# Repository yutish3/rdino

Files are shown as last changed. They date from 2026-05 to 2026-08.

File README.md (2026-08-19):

# Rdino - 2040
rp-2040 development board in the shape of arduino uno r3 so it supports its hats and also has esp32 for wifi and bluetooth and 5x5 grid of neo pixel leds

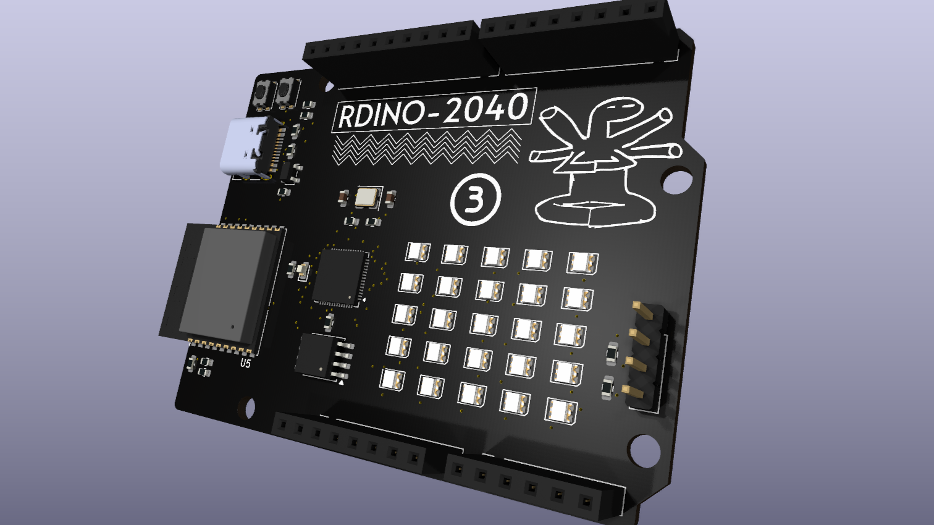
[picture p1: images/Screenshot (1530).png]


## VISION
main goals I had was making it is that I wanted to have a powerful board on which Arduino hats can fit with wireless capabilities so I used both rp 2040 and esp 32 and connected gpios of both so rp 2040 can off load some tasks to esp 32. so in a sense it is like Arduino UNO but on steroids 

and for usage too it can be used like a normal Arduino UNO 

it has dual microcontroller so all the less important repetative tasks can be off loaded to esp32 and main work can be done by the rp 2040 chip with extra 16M bit memory
and it can be used foor any project like lfr robot , micromouse , rc car etc

## what makes it special (main components)
&#9679; RP2040 :- main microcontroller

&#9679; W25Q128JVS :- 128Mbit Flash Memory for extra juice

&#9679; ESP32-C3-WROOM-02 :- backup microcontroller with wifi and Bluetooth capabilities 

&#9679; 25 X WS2812B-2020 :- programmable rgb leds

## Images

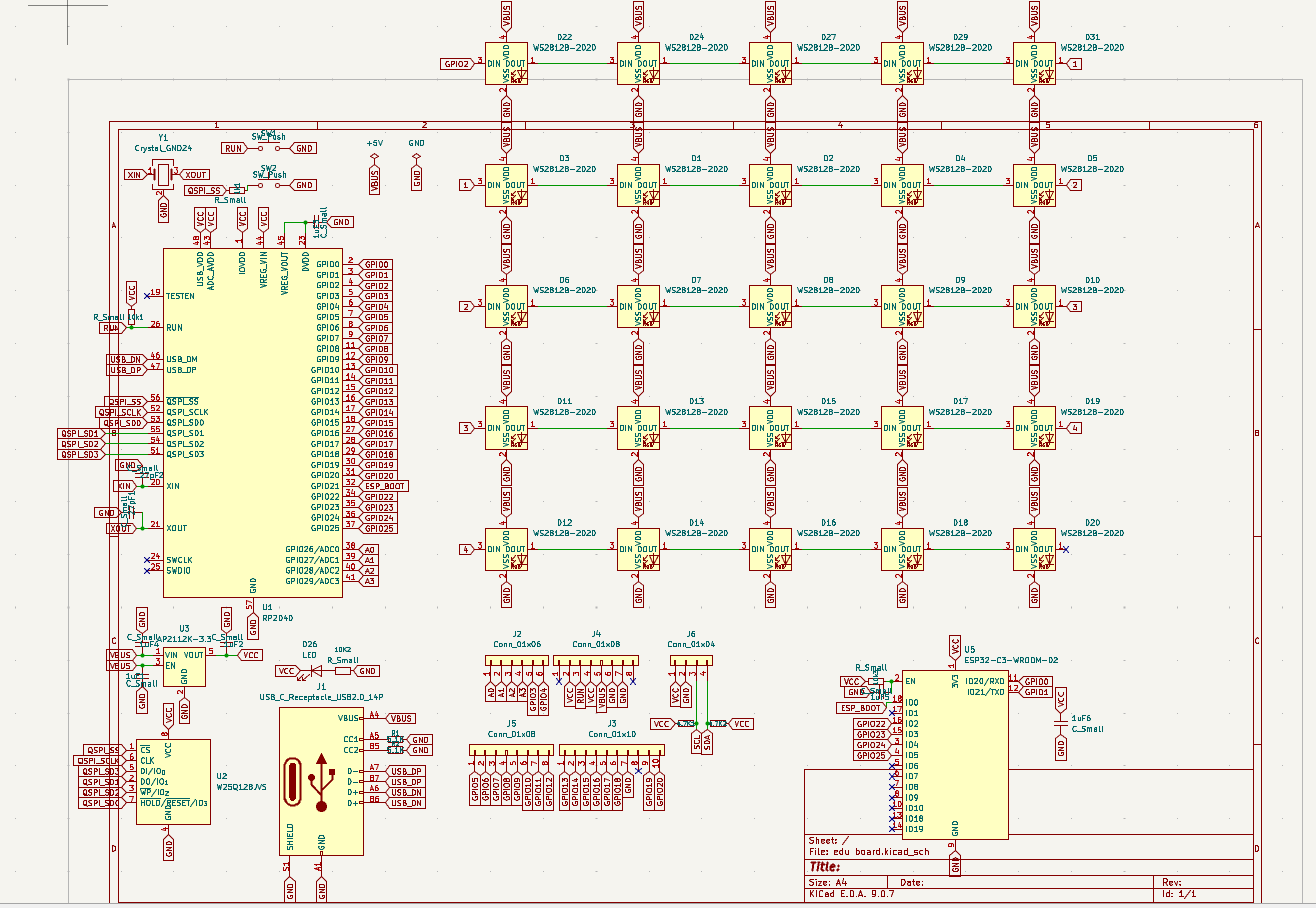
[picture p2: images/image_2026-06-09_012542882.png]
Schematics


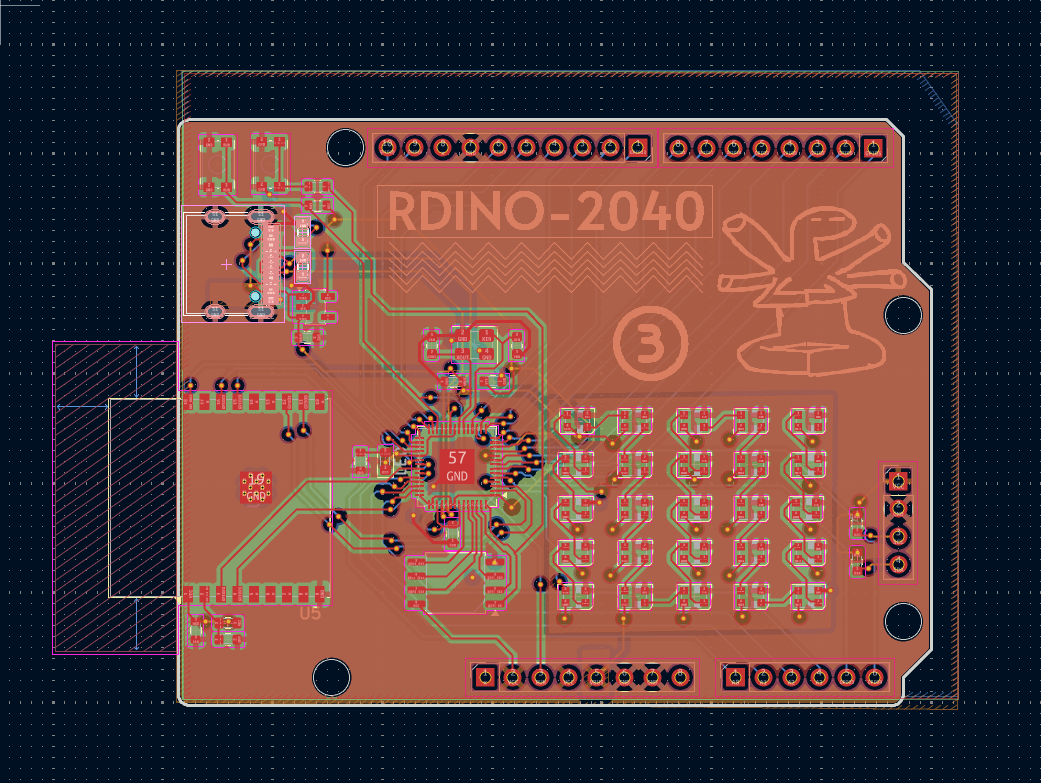
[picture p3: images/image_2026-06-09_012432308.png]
PCB design


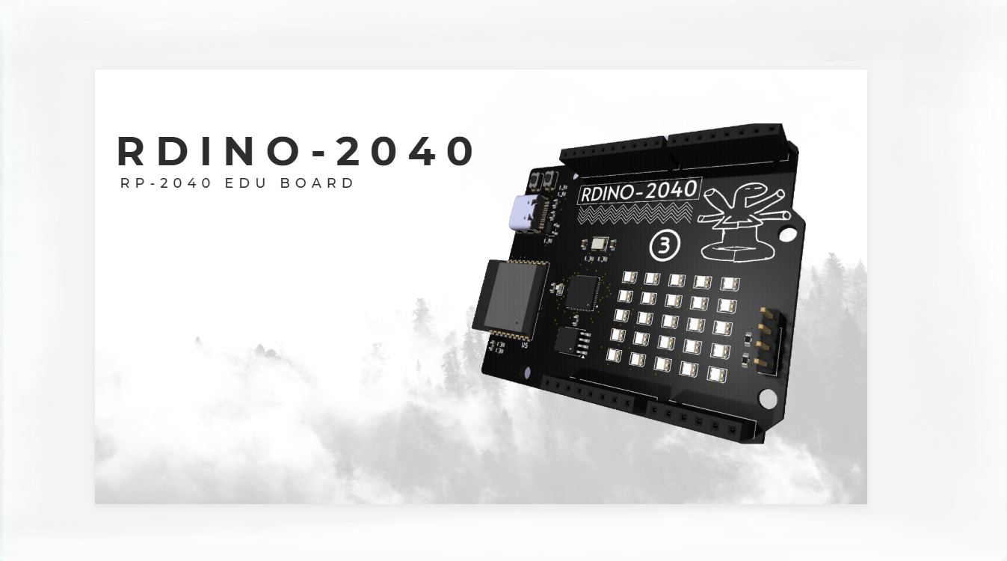
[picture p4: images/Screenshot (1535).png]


PCB Layout 1

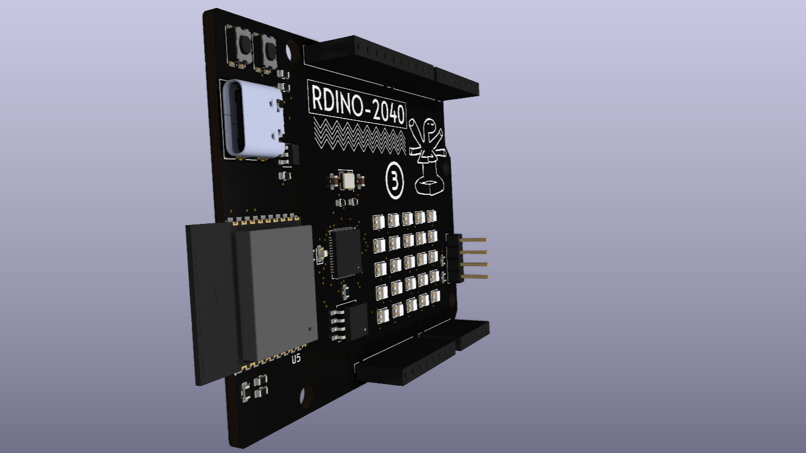
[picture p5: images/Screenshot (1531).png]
PCB Layout 2


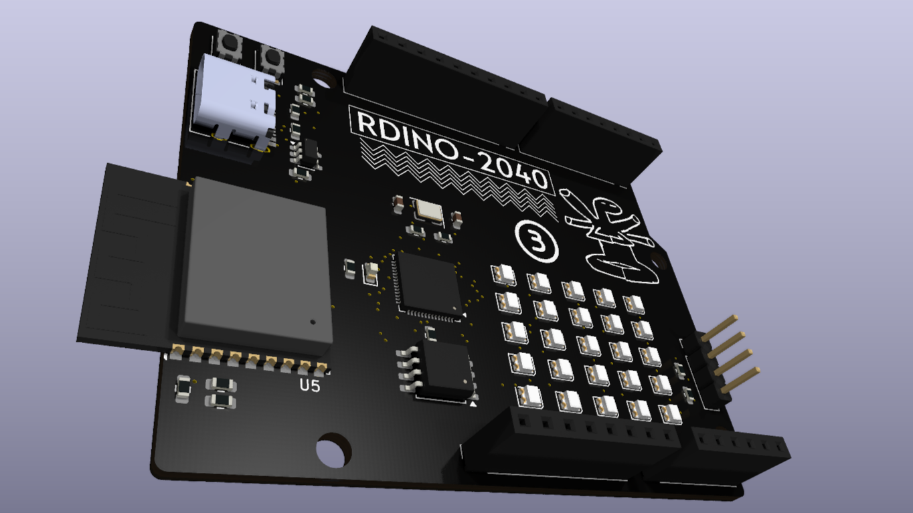
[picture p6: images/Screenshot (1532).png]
DRC Errors


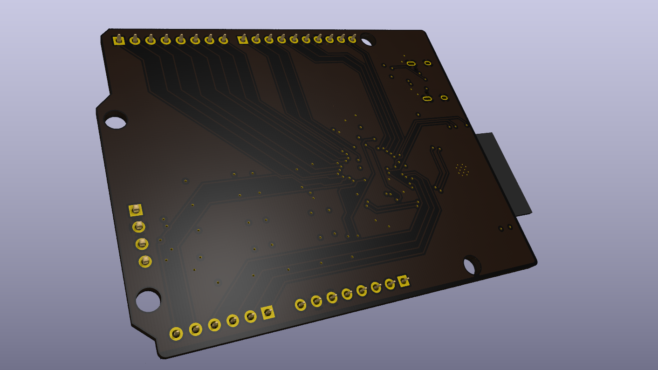
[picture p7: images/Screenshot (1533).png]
Silkscreen Design


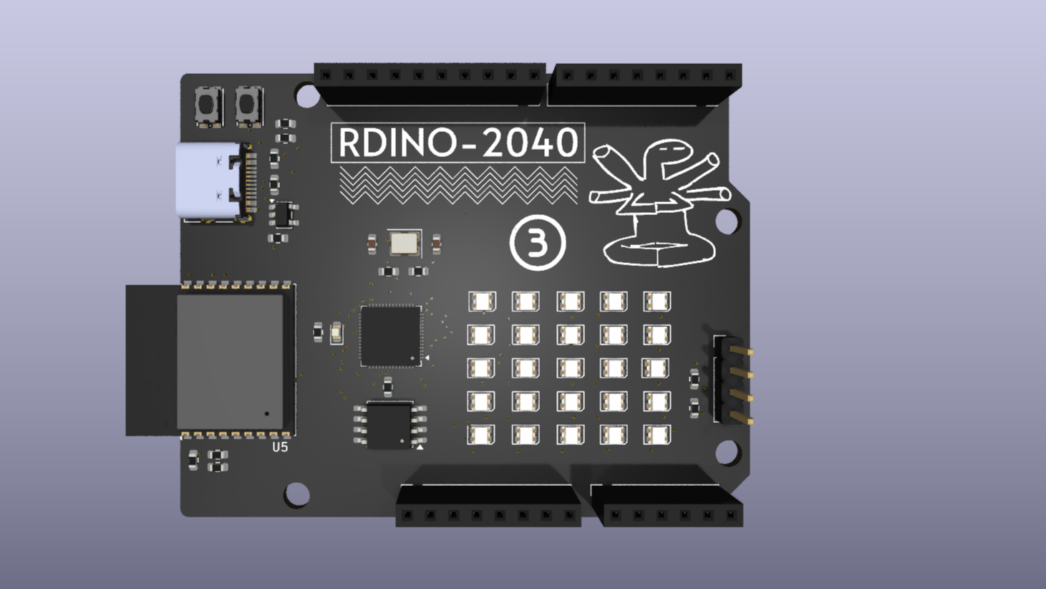
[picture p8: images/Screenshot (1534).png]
3D View


| Component | Purpose | Qty | Cost (INR) | Distributor |
| --- | --- | --- | --- | --- |
| RP2040 (QFN-56) | Main Microcontroller | 1 | ₹81.00 | [Evelta](https://evelta.com/rp2040-264kb-sram-dual-arm-cortex-m0-processor-mcu-by-raspberry-pi/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) |
| ESP32-C3-WROOM-02 | Wi-Fi / BLE Module | 1 | ₹312 | [Evelta](https://evelta.com/esp32-c3-wroom-02-n4-wi-fi-ble-module-4mb-flash-pcb-antenna/?sku=136-ESP32-C3-WROOM-02-N4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) |
| W25Q128JVS (SOIC-8) | 128Mbit Flash Memory | 1 | ₹223 | [Evelta](https://evelta.com/serial-nor-flash-memory-128mbit-8pin-soic/?sku=153-W25Q128JVSIQ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) |
| AP2112K-3.3 (SOT-23-5) | 3.3V LDO Voltage Regulator | 1 | ₹24 | [Evelta](https://evelta.com/linear-voltage-regulator-positive-fixed-1-output-300ma-ic-sot-23-5/?sku=035-TLV74033PDBVR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) |
| WS2812B-2020 (PLCC4) | Addressable RGB LEDs (D1-D24, D27, D29, D31) | 25 | ₹275 | [Robu](https://robu.in/product/1-month-warranty-953/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) |
| 74AHCT125 | 3.3v to 5v converter | 1 | ₹113 | [Lioncircuit](https://www.lioncircuits.com/parts/74AHCT125PW%2C118) |
| Standard LED (0603) | Status Indicator (D26) | 1 | ₹3.3 | [evelta](https://evelta.com/0603-orange-chip-led/?srsltid=AfmBOopJK48IT0WFYCzFETDcCPIIkiPRop17X2j5vajIVfQTBZ31vxPa) |
| USB-C Receptacle 14-Pin | Power and Data Interface (J1) | 1 | ₹8 | [Hubtronics](https://hubtronics.in/usb-type-c-16p-female-connector-surface-mount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) |
| 1x04 Pin Header/Socket | I/O Expansion / Programming (J6) | 1 | ₹11 | [Robu](https://robu.in/product/fh2-0-09-04pzd-xunpu-plugin1x4-pin-2mm-female-headers-rohs/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)|
| 1x06 Pin Header/Socket | I/O Expansion (J2) | 5 | ₹53 | [Robu](https://robu.in/product/6-pin-female-11mm-tall-stackable-header-connector-for-arduino-5pcs/) |
| 1x08 Pin Header/Socket | I/O Expansion (J4, J5) | 2 | ₹32 | [Robu](https://robu.in/product/fh1-27-01-08pzd-xunpu-plugin1x8-pin-1-27mm-female-headers-rohs/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) |
| 1x10 Pin Header/Socket | I/O Expansion (J3) | 1 | ₹17 | [Robu](https://robu.in/product/fh1-27-01-10pzd-xunpu-plugin1x10-pin-1-27mm-female-headers-rohs/) |
| Push Button (KMR2) | Reset / User Input (SW1, SW2) | 2 | ₹126 | [Robu](https://robu.in/product/kmr221nglfs-ck-2-8mm-0-5mm-round-button-50ma-vertical-welding-4-2mm-spst-2n-32v-smd-tactile-switches-rohs/) |
| 1.1kΩ Resistor (0603) | Current Limiting / Pull-up | 1 | ₹1 | [Robu](https://robu.in/product/0603waj0112t5e-uniohm-royal-ohm-100mw-thick-film-resistors-75v-%C2%B1100ppm-%E2%84%83%C2%B15-1-1k%CF%89-0603-chip-resistor-surface-mount-rohs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) |
| 4.7kΩ Resistor (0603) | I2C / General Pull-up | 2 | ₹5 | [Robu](https://robu.in/product/rt0603brd074k7l-yageo-res-thin-film-0603-4-7k-ohm-0-1-0-1w1-10w-%C2%B125ppm-c-pad-smd-t-r/) |
| 10kΩ Resistor (0603) | Pull-up / Pull-down | 3 | ₹3 | [Robu](https://robu.in/product/10k-ohm-1-4w-0603-surface-mount-chip-resistor-pack-of-100/) |
| 5.1kΩ Resistor (0603) | USB-C CC line Pull-down | 2 | ₹3 | [Robu](https://robu.in/product/rt0603fre075k1l-yageo-100mw-thin-film-resistor-75v-%C2%B150ppm-%E2%84%83-%C2%B11-5-1k%CF%89-0603-chip-resistor-surface-mount-rohs/) |
| 1μF Capacitor (0603) | Decoupling / Bypass | 6 | ₹8.5 | [Robu](https://robu.in/product/1uf-1000nf-50v-capacitor-0603-smd-package-pack-of-20/) |
| 10pF Capacitor (0603) | Crystal Load Capacitors | 2 | ₹1 | [Robu](https://robu.in/product/10pf-0603-surface-mount-multilayer-ceramic-capacitor-pack-of-50/) |
| Crystal 3225 (4-Pin) | Clock Source for RP2040 (Y1) | 1 | ₹101 | [lion circuit](https://www.lioncircuits.com/parts/NX3225SA-12MHZ-STD-CSR-6) |
| PCB | PCB | 1 | ₹3375 | [Robu] |
| Hot plate | soldering | 1 | ₹2,749 | [Amazon](https://www.amazon.in/Preheating-Soldering-Preheater-Platform-56x56x35mm/dp/B0C7W3W8C4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) |
| soldering flux | gooye paste to combine components | 1 | ₹400 | [amazon](https://www.amazon.in/Electron-Soldering-Syringe-No-Clean-Electronics/dp/B0GTMJHBJ4) |

The Bare Components : ₹1,708.80

PCB Fabrication (Robu): ₹3,375.00

Assembly Tools (Amazon): ₹3,262.00

Grand Total: ₹8,345.8

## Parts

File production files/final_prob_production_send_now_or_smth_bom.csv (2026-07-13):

Designator | Footprint | Quantity | Value | LCSC Part #
10K1, 10K2, 10K3, 1K1, 4.7K1, 4.7K2 | 0603 | 6 | R_Small
10PF1, 10PF2, 1UF1, 1UF2, 1UF3, 1UF4, 1UF5, 1UF6 | 0603 | 8 | C_Small
D1, D10, D11, D12, D13, D14, D15, D16, D17, D18, D19, D2, D20, D22, D24, D27, D29, D3, D31, D4, D5, D6, D7, D8, D9 | LED_WS2812B-2020_PLCC4_2.0x2.0mm | 25 | WS2812B-2020
D26 | 0603 | 1 | LED
J1 | USB_C_Receptacle_HRO_TYPE-C-31-M-12 | 1 | USB_C_Receptacle_USB2.0_14P
J2 | PinSocket_1x06_P2.54mm_Vertical | 1 | Conn_01x06
J3 | PinSocket_1x10_P2.54mm_Vertical | 1 | Conn_01x10
J4, J5 | PinSocket_1x08_P2.54mm_Vertical | 2 | Conn_01x08
J6 | PinHeader_1x04_P2.54mm_Vertical | 1 | Conn_01x04
R1, R2 | 0603 | 2 | 5.1K
SW1, SW2 | SW_Push_1P1T_NO_CK_KMR2 | 2 | SW_Push
U1 | QFN-56-1EP_7x7mm_P0.4mm_EP3.2x3.2mm | 1 | RP2040
U2 | SOIC-8_5.3x5.3mm_P1.27mm | 1 | W25Q128JVS
U3 | SOT-23-5 | 1 | AP2112K-3.3
U4 | TSSOP-14_4.4x5mm_P0.65mm | 1 | 74AHCT125
U5 | ESP32-C3-WROOM-02 | 1 | ESP32-C3-WROOM-02
Y1 | Crystal_SMD_3225-4Pin_3.2x2.5mm | 1 | Crystal_GND24

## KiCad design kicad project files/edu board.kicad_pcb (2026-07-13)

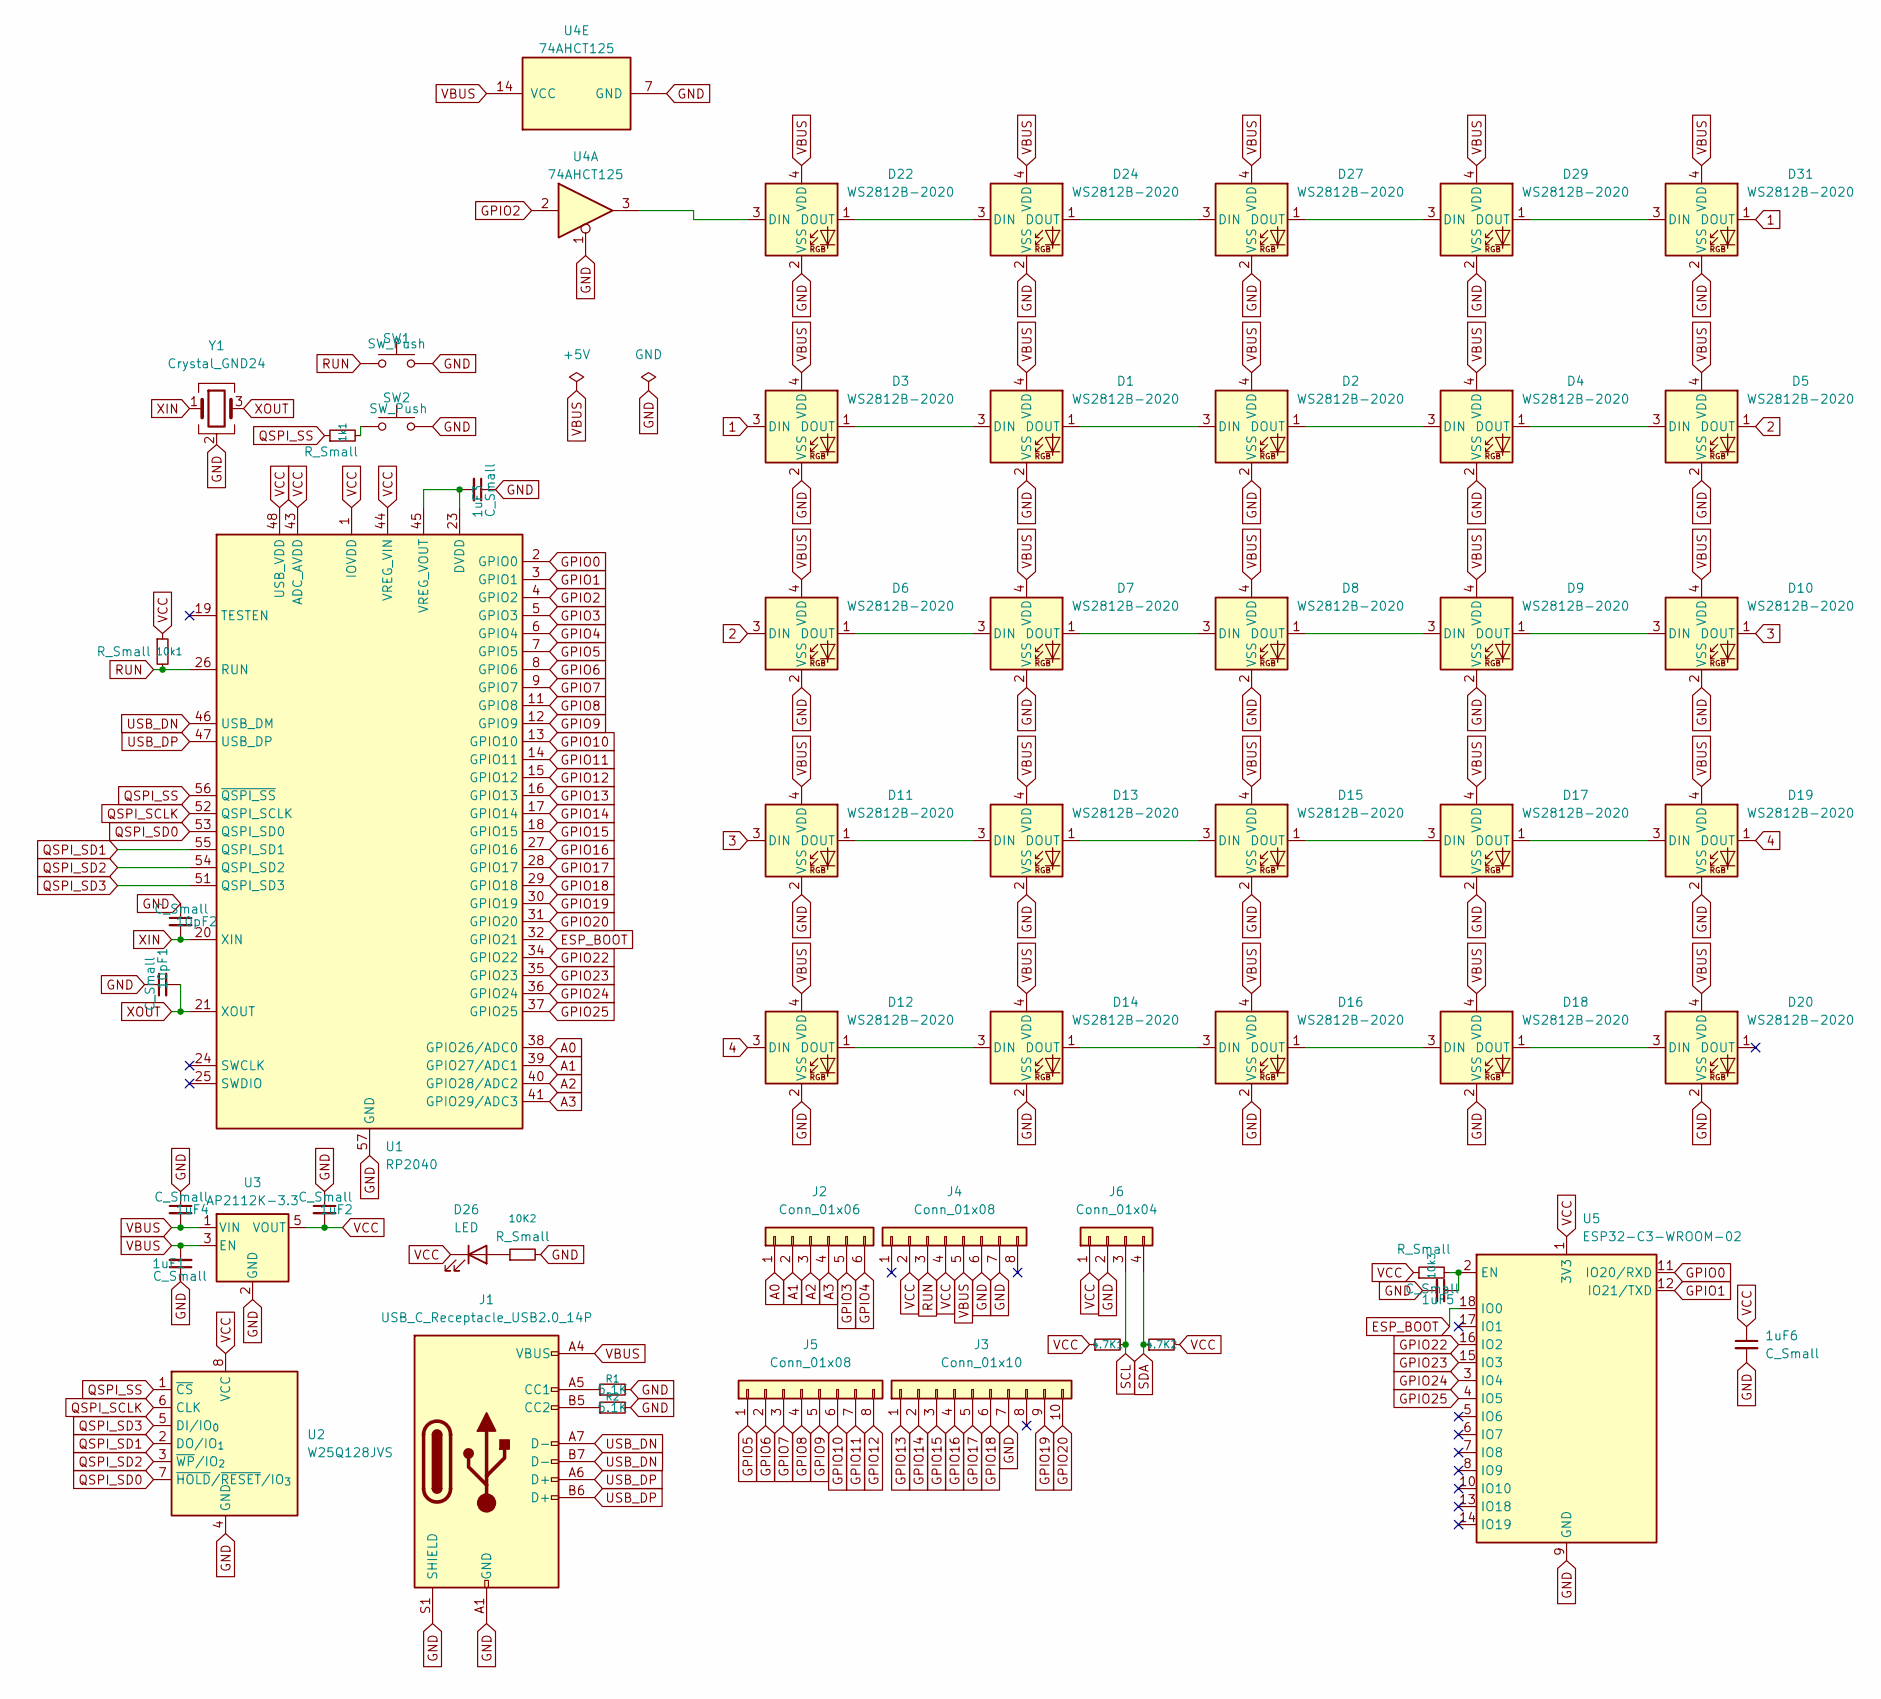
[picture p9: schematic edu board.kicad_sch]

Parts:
1k1, 4.7K1, 4.7K2, 10K2, 10k1, 10k3: R_Small; R_0603_1608Metric
1uF1, 1uF2, 1uF3, 1uF4, 1uF5, 1uF6, 10pF1, 10pF2: C_Small; C_0603_1608Metric
D1, D2, D3, D4, D5, D6, D7, D8, D9, D10, D11, D12, D13, D14, D15, D16, D17, D18, D19, D20, D22, D24, D27, D29, D31: WS2812B-2020; LED_WS2812B-2020_PLCC4_2.0x2.0mm
D26: LED; LED_0603_1608Metric
J1: USB_C_Receptacle_USB2.0_14P; USB_C_Receptacle_HRO_TYPE-C-31-M-12
J2: Conn_01x06; PinSocket_1x06_P2.54mm_Vertical
J3: Conn_01x10; PinSocket_1x10_P2.54mm_Vertical
J4, J5: Conn_01x08; PinSocket_1x08_P2.54mm_Vertical
J6: Conn_01x04; PinHeader_1x04_P2.54mm_Vertical
R1, R2: 5.1K; R_0603_1608Metric
SW1, SW2: SW_Push; SW_Push_1P1T_NO_CK_KMR2
U1: RP2040; QFN-56-1EP_7x7mm_P0.4mm_EP3.2x3.2mm
U2: W25Q128JVS; SOIC-8_5.3x5.3mm_P1.27mm
U3: AP2112K-3.3; SOT-23-5
U4: 74AHCT125; TSSOP-14_4.4x5mm_P0.65mm
U5: ESP32-C3-WROOM-02
Y1: Crystal_GND24; Crystal_SMD_3225-4Pin_3.2x2.5mm

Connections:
1: D3.3 (DIN), D31.1 (DOUT)
2: D5.1 (DOUT), D6.3 (DIN)
3: D10.1 (DOUT), D11.3 (DIN)
4: D12.3 (DIN), D19.1 (DOUT)
A0: J2.1, U1.38 (GPIO26/ADC0)
A1: J2.2, U1.39 (GPIO27/ADC1)
A2: J2.3, U1.40 (GPIO28/ADC2)
A3: J2.4, U1.41 (GPIO29/ADC3)
ESP_BOOT: U1.32 (GPIO21), U5.18 (IO0)
GND: 1uF1.1, 1uF2.1, 1uF3.1, 1uF4.1, 1uF5.2, 1uF6.2, 10K2.2, 10pF1.1, 10pF2.1, D1.2 (VSS), D2.2 (VSS), D3.2 (VSS), D4.2 (VSS), D5.2 (VSS), D6.2 (VSS), D7.2 (VSS), D8.2 (VSS), D9.2 (VSS), D10.2 (VSS), D11.2 (VSS), D12.2 (VSS), D13.2 (VSS), D14.2 (VSS), D15.2 (VSS), D16.2 (VSS), D17.2 (VSS), D18.2 (VSS), D19.2 (VSS), D20.2 (VSS), D22.2 (VSS), D24.2 (VSS), D27.2 (VSS), D29.2 (VSS), D31.2 (VSS), J1.A1 (GND), J1.A12 (GND), J1.B1 (GND), J1.B12 (GND), J1.S1 (SHIELD), J3.7, J4.6, J4.7, J6.2, R1.2, R2.2, SW1.2, SW2.2, U1.57 (GND), U2.4 (GND), U3.2 (GND), U4.1, U4.7 (GND), U5.9 (GND), U5.19 (GND), Y1.2 (G), Y1.4 (G)
GPIO0: U1.2 (GPIO0), U5.11 (IO20/RXD)
GPIO1: U1.3 (GPIO1), U5.12 (IO21/TXD)
GPIO2: U1.4 (GPIO2), U4.2
GPIO3: J2.5, U1.5 (GPIO3)
GPIO4: J2.6, U1.6 (GPIO4)
GPIO5: J5.1, U1.7 (GPIO5)
GPIO6: J5.2, U1.8 (GPIO6)
GPIO7: J5.3, U1.9 (GPIO7)
GPIO8: J5.4, U1.11 (GPIO8)
GPIO9: J5.5, U1.12 (GPIO9)
GPIO10: J5.6, U1.13 (GPIO10)
GPIO11: J5.7, U1.14 (GPIO11)
GPIO12: J5.8, U1.15 (GPIO12)
GPIO13: J3.1, U1.16 (GPIO13)
GPIO14: J3.2, U1.17 (GPIO14)
GPIO15: J3.3, U1.18 (GPIO15)
GPIO16: J3.4, U1.27 (GPIO16)
GPIO17: J3.5, U1.28 (GPIO17)
GPIO18: J3.6, U1.29 (GPIO18)
GPIO19: J3.9, U1.30 (GPIO19)
GPIO20: J3.10, U1.31 (GPIO20)
GPIO22: U1.34 (GPIO22), U5.16 (IO2)
GPIO23: U1.35 (GPIO23), U5.15 (IO3)
GPIO24: U1.36 (GPIO24), U5.3 (IO4)
GPIO25: U1.37 (GPIO25), U5.4 (IO5)
unnamed: 1k1.2, SW2.1
unnamed: D1.3 (DIN), D3.1 (DOUT)
unnamed: D1.1 (DOUT), D2.3 (DIN)
unnamed: D2.1 (DOUT), D4.3 (DIN)
unnamed: D4.1 (DOUT), D5.3 (DIN)
unnamed: D6.1 (DOUT), D7.3 (DIN)
unnamed: D7.1 (DOUT), D8.3 (DIN)
unnamed: D8.1 (DOUT), D9.3 (DIN)
unnamed: D9.1 (DOUT), D10.3 (DIN)
unnamed: D11.1 (DOUT), D13.3 (DIN)
unnamed: D12.1 (DOUT), D14.3 (DIN)
unnamed: D13.1 (DOUT), D15.3 (DIN)
unnamed: D14.1 (DOUT), D16.3 (DIN)
unnamed: D15.1 (DOUT), D17.3 (DIN)
unnamed: D16.1 (DOUT), D18.3 (DIN)
unnamed: D17.1 (DOUT), D19.3 (DIN)
unnamed: D18.1 (DOUT), D20.3 (DIN)
unnamed: D22.3 (DIN), U4.3
unnamed: D22.1 (DOUT), D24.3 (DIN)
unnamed: D24.1 (DOUT), D27.3 (DIN)
unnamed: 10K2.1, D26.2 (A)
unnamed: D27.1 (DOUT), D29.3 (DIN)
unnamed: D29.1 (DOUT), D31.3 (DIN)
unnamed: J1.A5 (CC1), R1.1
unnamed: J1.B5 (CC2), R2.1
unnamed: 1uF3.2, U1.23 (DVDD), U1.45 (VREG_VOUT), U1.50 (DVDD)
unnamed: 1uF5.1, 10k3.2, U5.2 (EN)
QSPI_SCLK: U1.52 (QSPI_SCLK), U2.6 (CLK)
QSPI_SD0: U1.53 (QSPI_SD0), U2.7 (~HOLD/~RESET/IO_{3})
QSPI_SD1: U1.55 (QSPI_SD1), U2.2 (DO/IO_{1})
QSPI_SD2: U1.54 (QSPI_SD2), U2.3 (~WP/IO_{2})
QSPI_SD3: U1.51 (QSPI_SD3), U2.5 (DI/IO_{0})
QSPI_SS: 1k1.1, U1.56 (~QSPI_SS), U2.1 (~CS)
RUN: 10k1.2, J4.3, SW1.1, U1.26 (RUN)
SCL: 4.7K1.2, J6.3
SDA: 4.7K2.1, J6.4
USB_DN: J1.A7 (D-), J1.B7 (D-), U1.46 (USB_DM)
USB_DP: J1.A6 (D+), J1.B6 (D+), U1.47 (USB_DP)
VBUS: 1uF1.2, 1uF4.2, D1.4 (VDD), D2.4 (VDD), D3.4 (VDD), D4.4 (VDD), D5.4 (VDD), D6.4 (VDD), D7.4 (VDD), D8.4 (VDD), D9.4 (VDD), D10.4 (VDD), D11.4 (VDD), D12.4 (VDD), D13.4 (VDD), D14.4 (VDD), D15.4 (VDD), D16.4 (VDD), D17.4 (VDD), D18.4 (VDD), D19.4 (VDD), D20.4 (VDD), D22.4 (VDD), D24.4 (VDD), D27.4 (VDD), D29.4 (VDD), D31.4 (VDD), J1.A4 (VBUS), J1.A9 (VBUS), J1.B4 (VBUS), J1.B9 (VBUS), J4.5, U3.1 (VIN), U3.3 (EN), U4.14 (VCC)
VCC: 1uF2.2, 1uF6.1, 4.7K1.1, 4.7K2.2, 10k1.1, 10k3.1, D26.1 (K), J4.2, J4.4, J6.1, U1.1 (IOVDD), U1.10 (IOVDD), U1.22 (IOVDD), U1.33 (IOVDD), U1.42 (IOVDD), U1.43 (ADC_AVDD), U1.44 (VREG_VIN), U1.48 (USB_VDD), U1.49 (IOVDD), U2.8 (VCC), U3.5 (VOUT), U5.1 (3V3)
XIN: 10pF2.2, U1.20 (XIN), Y1.1
XOUT: 10pF1.2, U1.21 (XOUT), Y1.3

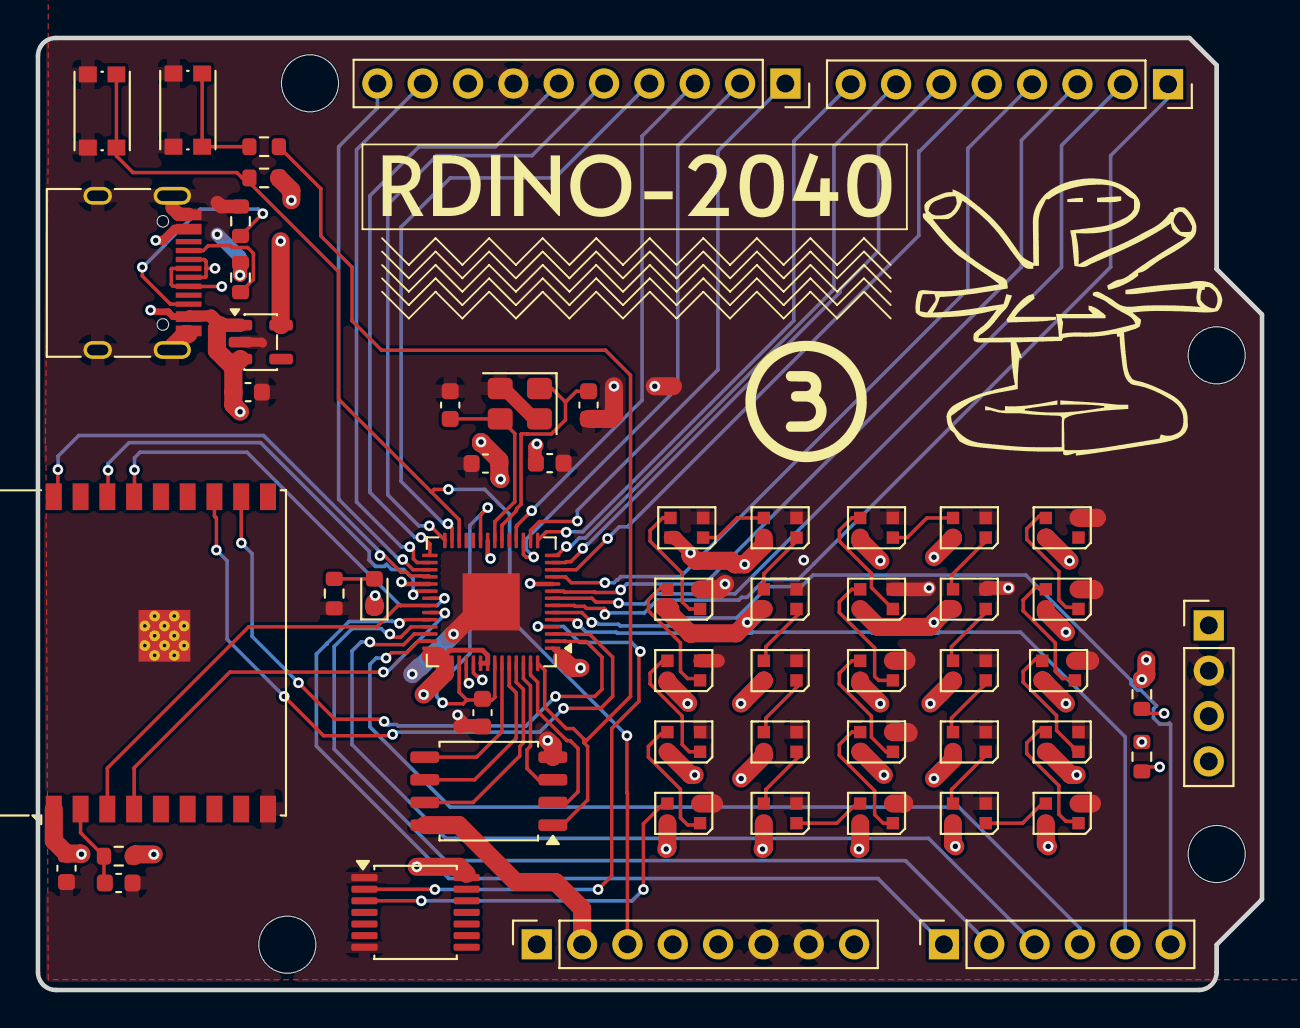
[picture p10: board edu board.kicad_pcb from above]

Board: 4 copper layers, 68.6 x 53.3 mm, 56 parts (0 on the bottom side), 77 nets.
